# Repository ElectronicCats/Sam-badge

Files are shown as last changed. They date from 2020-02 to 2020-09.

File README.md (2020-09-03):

# Badge Sam Dulces Sueños
## Reto de soldadura 

<a href="https://electroniccats.com/store/badge-sam-dulces-suenos/">
  
</a>

Divierte con nuestro nuevo Badge!, __“Sam dulces sueños”__ ha llegado y es increíblemente bonito y tierno. Está creado para enseñarte a soldar tu primera placa electrónica de componentes de soldado superficial SMD. ¿Aceptas el reto?.

Aunque originalmente este badge fue realizado para presentarse como taller en el evento de innovación y tecnología __“Talent Land 2020”__, no queríamos dejarte sin la experiencia de crear y aprender con nuestro aventurero amigo Sam, por lo tanto debido a la contingencia sanitaria el evento solo se realizará de manera virtual el próximo 8 y 9 de Julio en Iron Land @ Home. 

Nuestros amigos de **Wurth Electronics, Talent Land, PCBWay y Electronic Cats**, queremos regalarte uno de los 200 badge que tenemos disponibles, para que participes en este reto desde la comodidad de tu casa.

¡Nosotros ponemos la electrónica, tu solo paga el envío!. 

Lo único que debes hacer es cubrir el costo del envio hasta tu domicilio y tener en cuenta los requerimientos para participar. 
Una vez realizado el pedido, enviaremos tu badge y tendrás hasta el **3 de Julio del 2020** para subir a redes sociales tus  fotografías o videos de tu __“Sam dulces sueños”__ ensamblado y funcionando. Recuerda que deberás etiquetar a Wurth Electronics, Talend Land, PCBWay y Electronic Cats en tu post en cualquiera de nuestras redes sociales participantes. 

Redes sociales participantes:
- **"Instagram"** electroniccats/Whurth Electronics/PCBWay
- **"Twitter"** electronicats/Whurth Electronics/PCBWay
- **"Facebook"** electroniccats/Whurth Electronics/PCBWay

## Requerimientos:
- Se requieren conocimientos de nivel medio en electrónica y soldadura de componentes eléctricos para este kit, 
- Necesitas tener un programador ST LinkV2, Jlink o cualquier otro programador que soporte el protocolo SWIM.

### La Electrónica

¡Este kit tiene dos LED con diferentes patrones de luz y sorprendentes colores de PCB! 

Una vez que la placa es ensamblada, se debe programar con ST LinkV2 , Jlink o cualquier otro programador que soporte el protocolo SWIM por medio de su puerto SWD, los LEDs de la placa parpadearan y cambiará de color hasta que la batería se agote. El botón incluido en el kit te permite reiniciar el pequeño microcontrolador STM8.

Para más detalles, esquemáticos y firmware puedes consultar en nuestro repositorio de Github: https://github.com/ElectronicCats/Sam-badge

### Este kit contiene:

- 1 x Placa PCB Sam Durmiendo
- 1 x STM8S003F3P
- 4 x [LED RGB 156120M173000](https://www.mouser.mx/datasheet/2/445/156120M173000-1715570.pdf)
- 1 x Botón
- 1 x Resistencia 10K
- 1 x Capacitor 1uF
- 1 x Capacitor 0.1uF
- 1 x Soporte de batería CR2032
- NO INCLUYE BATERÍAS (batería CR2032)

## El Premio
Si eres uno de los 10 primeros participantes en subir a redes sociales tu video o fotos y nos etiquetas, te enviaremos un paquete de souvenirs de Wurth hasta las puertas de tu casa completamente gratis.

El **09 de Julio del 2020** anunciaremos durante la transmisión de Iron Land @ home a los ganadores del concurso en vivo y mostraremos su trabajo.

## Video de Ensamblado

IMAGE ALT TEXT HERE (https://www.youtube.com/watch?v=UkvUJHmSHjA)

## License
OpenSourceLicense

Electronic Cats invests time and resources providing this open source design, please support Electronic Cats and open-source hardware by purchasing products from Electronic Cats!

Designed by Electronic Cats.

Firmware released under an GNU AGPL v3.0 license. See the LICENSE file for more information.

Hardware released under an CERN Open Hardware Licence v1.2. See the LICENSE_HARDWARE file for more information.

Electronic Cats is a registered trademark, please do not use if you sell these PCBs.

Jun 2020

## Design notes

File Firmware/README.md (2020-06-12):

# Firmware

## Instalacion Rapida

- Por medio del ST Link V1 o V2, cargar el archivo [blink.ihx](https://github.com/ElectronicCats/Sam-badge/blob/master/Firmware/blink/blink.ihx)

## Instalacion Perzonalizada

- Instalar y configurar [Compilador SDCC](http://sdcc.sourceforge.net/)
- Descargar carpeta de Firmware
- Para saber como compilar puedes ver nuestro liveCats 

IMAGE ALT TEXT HERE (https://www.youtube.com/watch?v=aBqwMLnVHGw)

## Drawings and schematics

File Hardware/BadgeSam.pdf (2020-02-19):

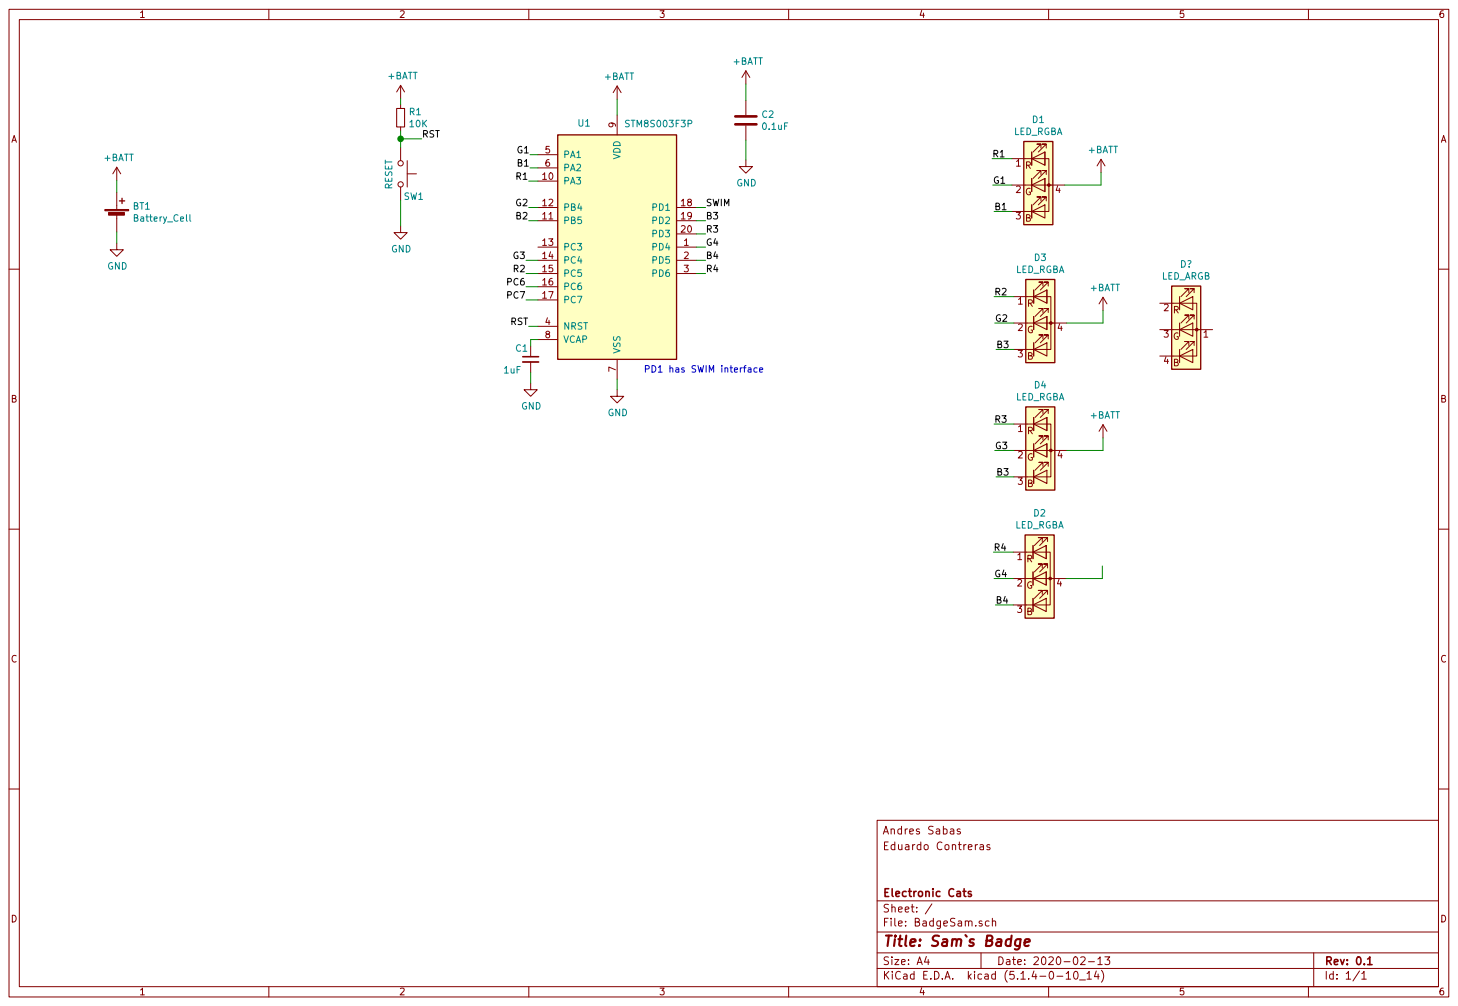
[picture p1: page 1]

Id: 1/1 Title: Sam`s Badge

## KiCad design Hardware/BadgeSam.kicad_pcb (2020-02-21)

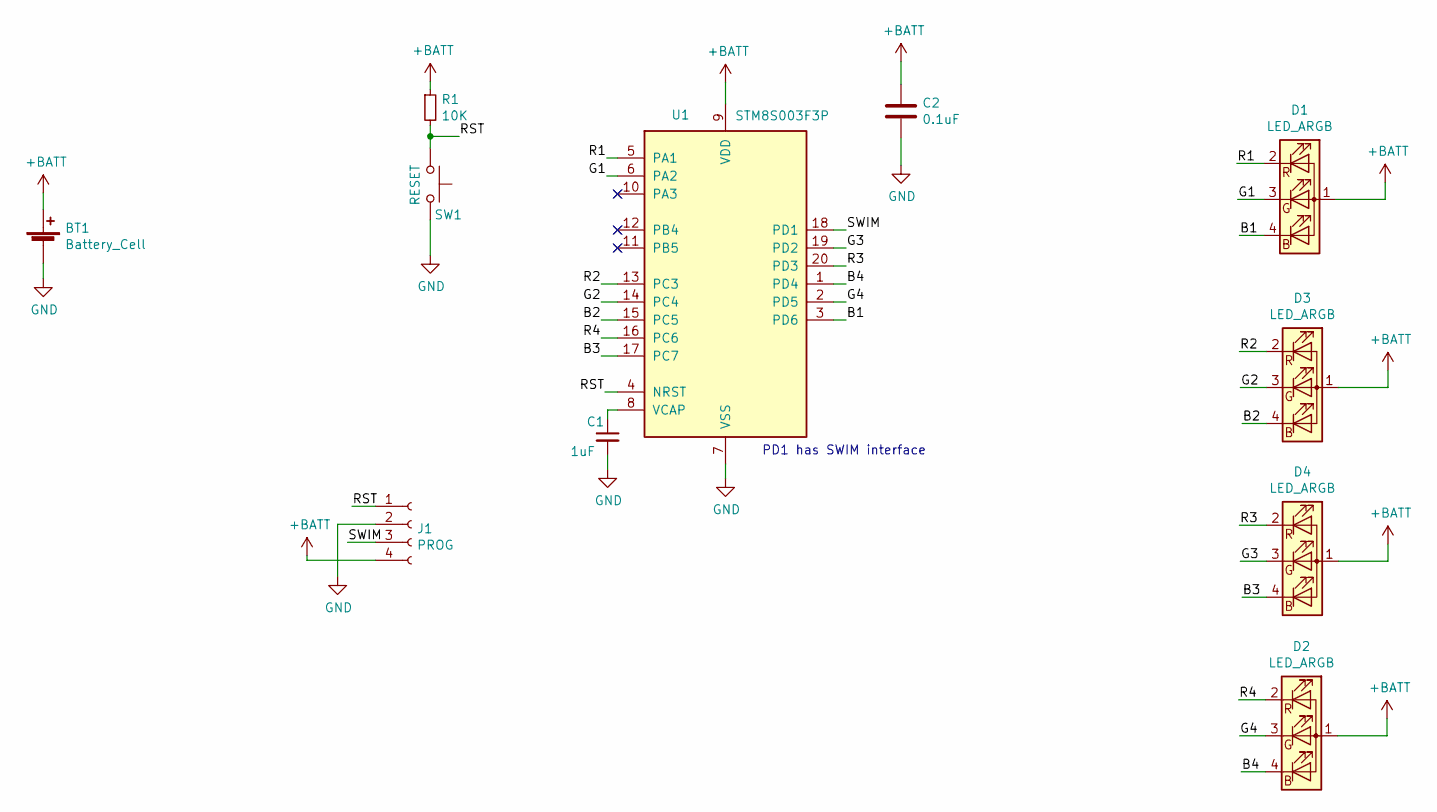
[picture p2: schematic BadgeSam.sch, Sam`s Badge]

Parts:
BT1: Battery_Cell; 79523141
C1: 1uF; C_0805_2012Metric_Pad1.15x1.40mm_HandSolder
C2: 0.1uF; C_0805_2012Metric_Pad1.15x1.40mm_HandSolder
D1, D2, D3, D4: LED_ARGB; 156120M173000
J1: PROG; PinHeader_1x04_P2.54mm_Vertical
R1: 10K; R_0805_2012Metric_Pad1.15x1.40mm_HandSolder
SW1: RESET; SW_SPST_TL3342
U1: STM8S003F3P; TSSOP-20_4.4x6.5mm_P0.65mm

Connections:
+BATT: BT1.1 (+), C2.1, D1.1 (A), D2.1 (A), D3.1 (A), D4.1 (A), J1.4, R1.1, U1.9 (VDD)
/B1: D1.4 (BK), U1.3 (PD6)
/B2: D3.4 (BK), U1.15 (PC5)
/B3: D4.4 (BK), U1.17 (PC7)
/B4: D2.4 (BK), U1.1 (PD4)
/G1: D1.3 (GK), U1.6 (PA2)
/G2: D3.3 (GK), U1.14 (PC4)
/G3: D4.3 (GK), U1.19 (PD2)
/G4: D2.3 (GK), U1.2 (PD5)
/R1: D1.2 (RK), U1.5 (PA1)
/R2: D3.2 (RK), U1.13 (PC3)
/R3: D4.2 (RK), U1.20 (PD3)
/R4: D2.2 (RK), U1.16 (PC6)
/RST: J1.1, R1.2, SW1.1, U1.4 (NRST)
/SWIM: J1.3, U1.18 (PD1)
GND: BT1.2 (-), C1.2, C2.2, J1.2, SW1.2, U1.7 (VSS)
unnamed: C1.1, U1.8 (VCAP)

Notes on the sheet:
PD1 has SWIM interface

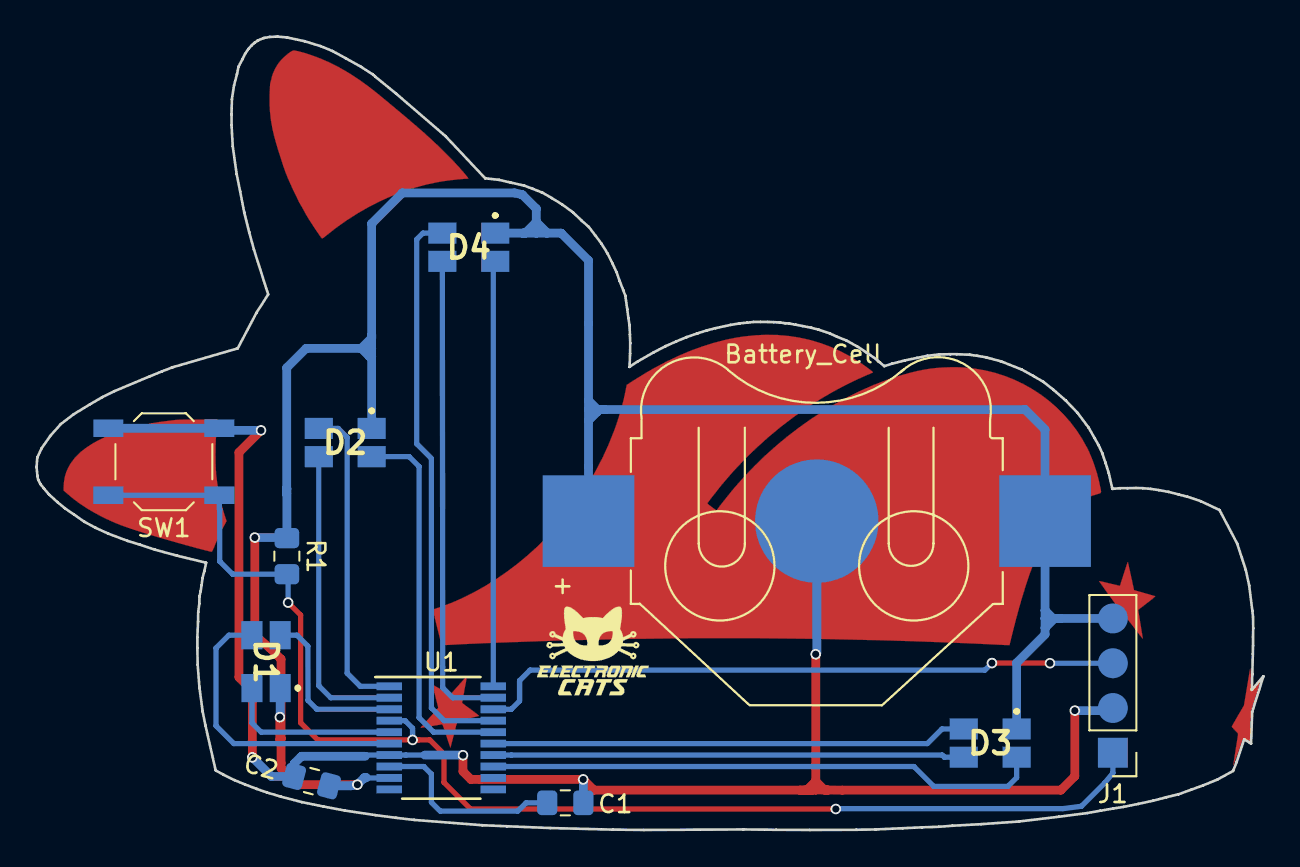
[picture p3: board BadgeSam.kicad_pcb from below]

Board: 2 copper layers, 69.6 x 45.0 mm, 12 parts (11 on the bottom side), 17 nets.

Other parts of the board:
Ref**: Val**; BadgeSam

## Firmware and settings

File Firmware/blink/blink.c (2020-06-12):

/* The "Hello world!" of microcontrollers. Blink LED on/off */
#include <stdint.h>
#include "stm8.h"


/* Build in LED is in pin B5 (STM8S103 board) or D3 (STM8S003F3 board) */

/*
LEDs pinout 

R1 = PA1
G1 = PA2
B1 = PD6

R2 = PC3
G2 = PC4
B2 = PC5

R3 = PD3
G3 = PD2
B3 = PC7

R4 = PC6
G4 = PD5
B4 = PD4
*/


#define LED_PORT    PA
#define LED_PIN     PIN2


/* Simple busy loop delay */
void delay(unsigned long count) {
    while (count--)
        nop();
}

int main(void)
{
    /* Set clock to full speed (16 Mhz) */
    CLK_CKDIVR = 4;

    /* GPIO setup All outputs*/
    PA_DDR = 0xF7; //PA3 not an output
    PC_DDR = 0xFF;
    PD_DDR = 0xFD; //PD1 not an output

    PA_CR1 = 0xFF;
    PC_CR1 = 0xFF;
    PD_CR1 = 0xFF;

    PA_ODR = 0x00;
    PC_ODR = 0x00;
    PD_ODR = 0x00;
    // Set pin data direction as output
    // PORT(LED_PORT, DDR)  |= LED_PIN; // i.e. PB_DDR |= (1 << 5);
    // Set pin as "Push-pull"
    // PORT(LED_PORT, CR1)  |= LED_PIN; // i.e. PB_CR1 |= (1 << 5);

	while(1) {
        // LED on
        
        
        //PORT(LED_PORT, ODR) |= LED_PIN; // PB_ODR |= (1 << 5);
        PA_ODR = 0xFF;
        PD_ODR = 0x00;
        PC_ODR = 0xAA;
        delay(10000L);
        // LED off
        //PORT(LED_PORT, ODR) &= ~LED_PIN; // PB_ODR &= ~(1 << 5);
        PA_ODR = 0x00;
        PD_ODR = 0x8A;
        PC_ODR = 0x55;
        delay(10000L);

        PA_ODR = 0xAA;
        PD_ODR = 0x56;
        PC_ODR = 0xAA;
        delay(10000L);

        PA_ODR = 0x55;
        PD_ODR = 0x00 ;
        PC_ODR = 0x5A;
        delay(10000L);
        
    }
}

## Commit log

2020-02-13 Initial pcb
    [BadgeSam.kicad_pcb]
2020-02-13 add r g b and button
    [BadgeSam.sch]
2020-02-14 add logo wurth
    [BadgeSam.kicad_pcb]
2020-02-14 add library for badge sam and battery holder
    [BadgeSam.sch]
2020-02-14 add footprint LED
2020-02-15 define size
    [BadgeSam.kicad_pcb, BadgeSam.sch]
2020-02-17 Add EdgeCut and logos
    [BadgeSam.kicad_pcb]
2020-02-17 fix routeo
    [BadgeSam.kicad_pcb]
2020-02-19 change rgb and footprint led
    [BadgeSam.kicad_pcb, BadgeSam.sch]
2020-02-20 routeo and pin prog
    [BadgeSam.kicad_pcb, BadgeSam.sch]
2020-02-20 fix track batt
    [BadgeSam.kicad_pcb]
2020-02-20 Fix leds and traces
    [BadgeSam.kicad_pcb, BadgeSam.sch]
2020-02-21 add pcbway logo
    [BadgeSam.kicad_pcb]
2020-06-02 fix path
    [BadgeSam.kicad_pcb, BadgeSam.sch]
2020-06-04 update BOM list
